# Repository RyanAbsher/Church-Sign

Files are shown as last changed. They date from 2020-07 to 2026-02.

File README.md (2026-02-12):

# Church Sign Controller

## Introduction
The **Church Sign Controller** is an ESP32-based wireless system designed to synchronize service status across multiple church buildings. This system allows a user in the main sanctuary to update the status of three remote signs in the nursery or classrooms, ensuring everyone is informed about the progress of the service.

## System Overview
The system utilizes the **ESP-NOW** protocol for communication between the controller and the signs. It supports four distinct states to communicate service progress:

* **Green:** Service is in progress.
* **Yellow:** Service is wrapping up (e.g., the band is on stage).
* **Red:** Service is over.
* **Off:** System is idle.

---

## Hardware Specifications

### The Controller
* **Module:** Built around an ESP32 with a touch display.
* **Interface:** Features an integrated LCD touchscreen for state selection.
* **Power:** Battery-powered with a dedicated wake button.
* **Power Management:** Enters sleep mode after 5 seconds of inactivity to conserve battery.

### The Signs
* **Module:** Based on ESP32 modules.
* **LEDs:** 12 WS2812B addressable LEDs per sign.
* **Power:** Powered by a 5V external power supply.

---

## Functional Behavior

### Controller GUI
* **Monitoring:** The screen is divided into three sections to show the current state, color, and communication status (including errors) for each sign.
* **Controls:** Includes four state buttons and a full-width "Save" button to store the current state in the controller's memory.
* **Sync:** All signs are updated to the same state simultaneously.

### Sign Animation & Logic
* **Visual Alerts:** When switching to Green, Yellow, or Red, the signs perform a flashing sequence before turning solid to ensure the change is noticed.
* **Idle Transition:** Switching to "Off" turns the LEDs off immediately without a flash pattern.
* **Safety Timeout:** Signs automatically turn off if they remain active for more than 8 hours.

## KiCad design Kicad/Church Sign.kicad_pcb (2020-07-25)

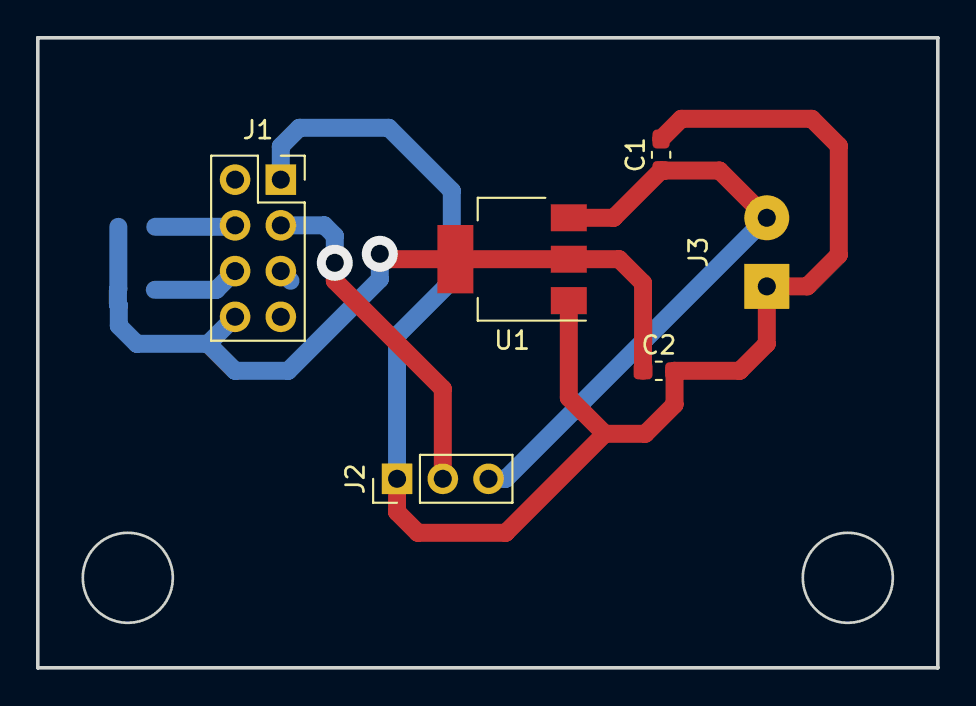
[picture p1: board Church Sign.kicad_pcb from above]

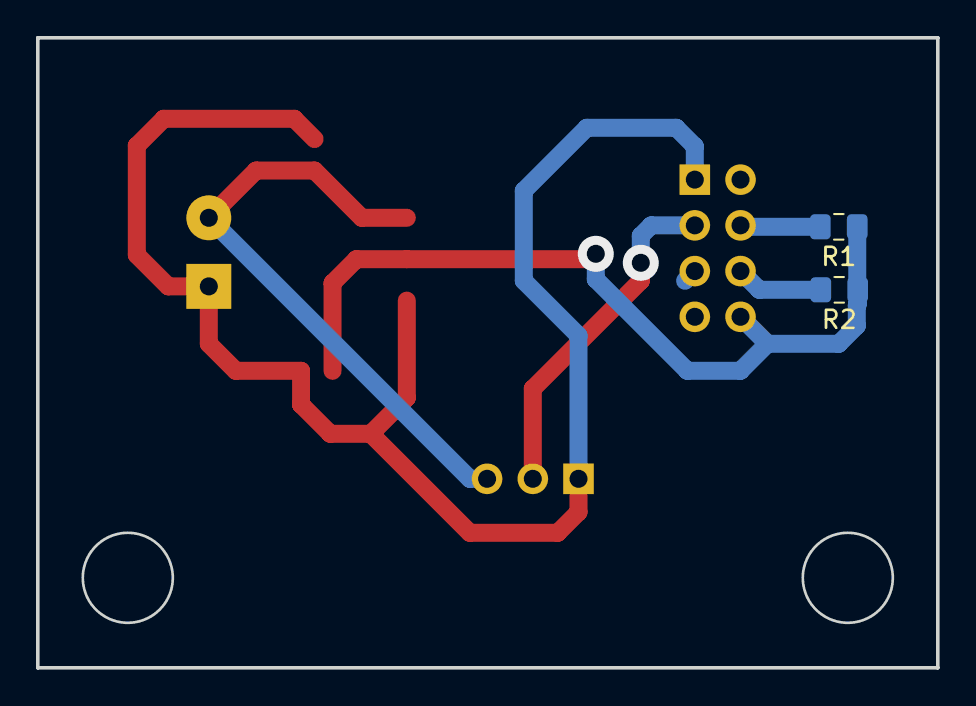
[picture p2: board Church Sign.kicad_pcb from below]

Board: 2 copper layers, 50.0 x 35.0 mm, 8 parts (2 on the bottom side), 6 nets.

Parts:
C1, C2: 0.1uF; C_0603_1608Metric_Pad1.05x0.95mm_HandSolder
J1: ESP Header; PinSocket_2x04_P2.54mm_Vertical
J2: To LEDs; PinHeader_1x03_P2.54mm_Vertical
J3: 5V In; SolderWirePad_1x02_P3.81mm_Drill1mm
R1, R2: 10k; R_0805_2012Metric_Pad1.15x1.40mm_HandSolder
U1: AZ1117-3.3; SOT-223-3_TabPin2

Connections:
+3V3: C2.1, J1.8, R1.1, R2.1, U1.2
+5V: C1.1, J2.3, J3.2, U1.3
/LED_DATA: J1.3, J2.2
GND: C1.2, C2.2, J1.1, J2.1, J3.1, U1.1
unnamed: J1.4, R1.2
unnamed: J1.6, R2.2

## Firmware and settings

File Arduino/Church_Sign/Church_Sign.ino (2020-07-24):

#include <ESP8266WiFi.h>
#include <ESP8266mDNS.h>
#include <FastLED.h>
#include <ESP8266WebServer.h>

#ifndef STASSID
//#define STASSID "BobNet_Down"
//#define STAPSK  "TurtleBusMothArm"
#define STASSID "SmartRG4cfe"
#define STAPSK  "3c9066494cfe"
#endif

int n; //Available services

const char* ssid     = STASSID;
const char* password = STAPSK;
char hostString[16] = {0};

ESP8266WebServer server(80);

#define NUM_LEDS 25
#define DATA_PIN 2

CRGB leds[NUM_LEDS];

int curColor = 0;

unsigned long partyTimer = 0;

void discover()
{
  Serial.println("Sending mDNS query");
  n = MDNS.queryService("sign", "tcp"); // Send out query for esp tcp services
  Serial.println("mDNS query done");
  if (n == 0) {
    Serial.println("no services found");
  } else {
    Serial.print(n);
    Serial.println(" service(s) found");
    for (int i = 0; i < n; ++i) {
      // Print details for each service found
      Serial.print(i + 1);
      Serial.print(": ");
      Serial.print(MDNS.hostname(i));
      Serial.print(" (");
      Serial.print(MDNS.IP(i));
      Serial.print(":");
      Serial.print(MDNS.port(i));
      Serial.println(")");
    }
  }
  Serial.println();

  Serial.println("loop() next");
}

void handleSentVar() {
  if (server.hasArg("color"))
  { // this is the variable sent from the client
    curColor = server.arg("color").toInt();
    server.send(200, "text/html", "Data received");
    if(curColor == 0)
    {
      fill_solid(leds, NUM_LEDS, CRGB::Black);
      FastLED.show();
    }
    else if(curColor == 1)
    {
      FastLED.setBrightness(255);
      fill_solid(leds, NUM_LEDS, CRGB::Green);
      FastLED.show();
      delay(250);
      fill_solid(leds, NUM_LEDS, CRGB::Black);
      FastLED.show();
      delay(250);
      fill_solid(leds, NUM_LEDS, CRGB::Green);
      FastLED.show();
      delay(250);
      fill_solid(leds, NUM_LEDS, CRGB::Black);
      FastLED.show();
      delay(250);
      fill_solid(leds, NUM_LEDS, CRGB::Green);
      FastLED.show();
    }
    else if(curColor == 2)
    {
      FastLED.setBrightness(255);
      fill_solid(leds, NUM_LEDS, CRGB::Yellow);
      FastLED.show();
      delay(250);
      fill_solid(leds, NUM_LEDS, CRGB::Black);
      FastLED.show();
      delay(250);
      fill_solid(leds, NUM_LEDS, CRGB::Yellow);
      FastLED.show();
      delay(250);
      fill_solid(leds, NUM_LEDS, CRGB::Black);
      FastLED.show();
      delay(250);
      fill_solid(leds, NUM_LEDS, CRGB::Yellow);
      FastLED.show();
    }
    else if(curColor == 3)
    {
      FastLED.setBrightness(255);
      fill_solid(leds, NUM_LEDS, CRGB::Red);
      FastLED.show();
      delay(250);
      fill_solid(leds, NUM_LEDS, CRGB::Black);
      FastLED.show();
      delay(250);
      fill_solid(leds, NUM_LEDS, CRGB::Red);
      FastLED.show();
      delay(250);
      fill_solid(leds, NUM_LEDS, CRGB::Black);
      FastLED.show();
      delay(250);
      fill_solid(leds, NUM_LEDS, CRGB::Red);
      FastLED.show();
    }
    Serial.print("CurColor: ");
    Serial.println(curColor);
    }
}

void setup()
{

  FastLED.addLeds<WS2812B, DATA_PIN, GRB>(leds, NUM_LEDS);

  fill_solid(leds, NUM_LEDS, CRGB::Black);

  FastLED.show();
  
  Serial.begin(115200);
  delay(100);
  Serial.println("\r\nsetup()");

  sprintf(hostString, "Sign_KIA");
  Serial.print("Hostname: ");
  Serial.println(hostString);
  WiFi.hostname(hostString);

  WiFi.mode(WIFI_STA);
  WiFi.begin(ssid, password);
  while (WiFi.status() != WL_CONNECTED) {
    delay(250);
    Serial.print(".");
  }
  Serial.println("");
  Serial.print("Connected to ");
  Serial.println(ssid);
  Serial.print("IP address: ");
  Serial.println(WiFi.localIP());

  if (!MDNS.begin(hostString)) {
    Serial.println("Error setting up MDNS responder!");
  }
  Serial.println("mDNS responder started");
  MDNS.addService("sign", "tcp", 8080); // Announce esp tcp service on port 8080

  fill_solid(leds, NUM_LEDS, CRGB::Red);
  FastLED.show();
  delay(250);
  fill_solid(leds, NUM_LEDS, CRGB::Green);
  FastLED.show();
  delay(250);
  fill_solid(leds, NUM_LEDS, CRGB::Blue);
  FastLED.show();
  delay(250);
  fill_solid(leds, NUM_LEDS, CRGB::Black);
  FastLED.show();

  discover();

  server.on("/data/", HTTP_GET, handleSentVar); // when the server receives a request with /data/ in the string then run the handleSentVar function
  server.begin();
}
  

void loop()
{
  // put your main code here, to run repeatedly:
  MDNS.update();
  server.handleClient();
  if(curColor == 4)
  {
    if(partyTimer == 0)
    {
      partyTimer = millis() + 300;
      
    }
    
    if(millis() >= partyTimer)
    {
      int red = random(0, 255);
      int green = random(0, 255);
      int blue = random(0, 255);
      FastLED.setBrightness(255);
      fill_solid(leds, NUM_LEDS, CRGB(red, green, blue));
      FastLED.show();
      for(int i = 255; i > 0; i=i-10)
      {
        FastLED.setBrightness(i);
        FastLED.show();
        delay(5);
      }
      partyTimer = 0;
    }
  }
  
}

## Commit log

2020-07-24 Initial Commit
    I created a new blank KiCAD project, as the original project was lost. The original Arduino code was saved, and is includede here.
    [Church Sign.kicad_pcb, Church Sign.sch]
2020-07-24 Redesign
    Since the original design was lost, I completely redesigned the PCB. The newer design is much smaller and more compact. It uses a 2 layer board instead of a single layer.
    [_saved_Church Sign.sch]
2020-07-24 Changes
    Moved ESP header traces to back layer.
    [Church Sign.kicad_pcb, Church Sign.sch, _saved_Church Sign.sch]
2020-07-24 Moved LED Pin
    Moved the LED data pin from IO0 to IO2.
    [Church Sign.kicad_pcb, Church Sign.sch]
